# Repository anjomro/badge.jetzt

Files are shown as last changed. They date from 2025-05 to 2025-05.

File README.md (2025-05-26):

# badge.jetzt

## How to build the badge hardware

1. Get the PCB
2. Solder the ESP32-C3 module to the PCB
3. Solder the WS2812B LEDs to the PCB
   1. The LEDs have a white corner on one corner, this needs to be on the top left corner for both LEDs
4. Solder the OLED Display to the PCB
5. Solder the buttons to the PCB
6. Flash the software to the ESP32-C3 module
   1. Install [platformio](https://platformio.org/platformio-ide) or the [CLI](https://docs.platformio.org/en/latest/core/index.html)
   2. Clone the repository: `git clone git@github.com:anjomro/badge.jetzt.git`
   3. Upload the project, run `pio run -t upload`

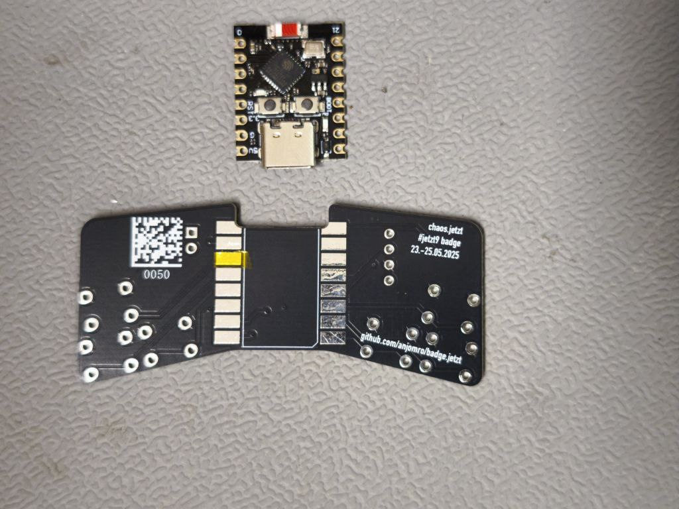
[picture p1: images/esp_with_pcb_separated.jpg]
ESP-C3 with PCB ESP-C3 with PCB separated

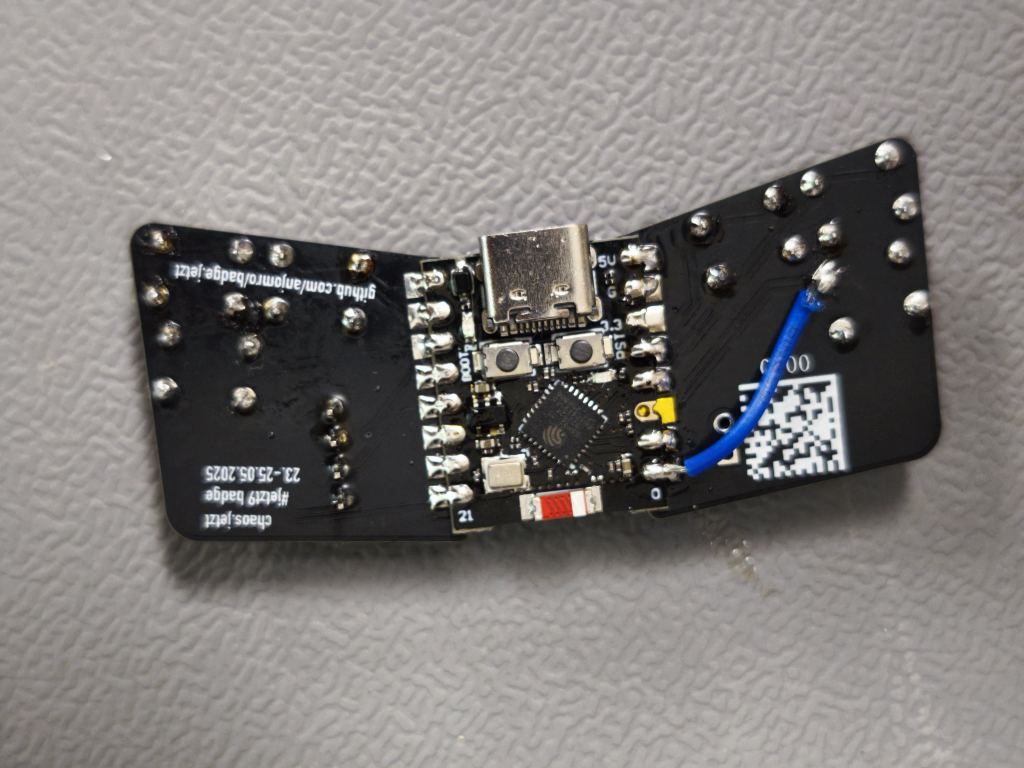
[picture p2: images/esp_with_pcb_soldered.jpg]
ESP-C3 with PCB soldered

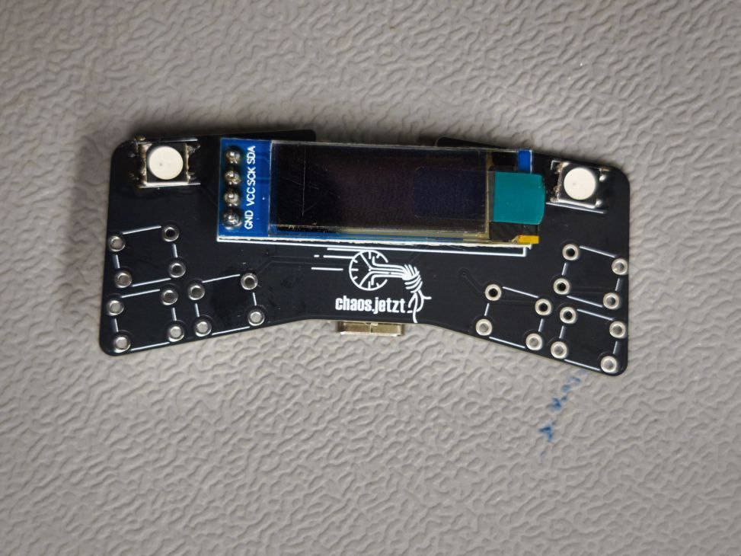
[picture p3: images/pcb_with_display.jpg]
PCB front with display PCB with display soldered on ti


## PlatformIO on different Systems:
**Arch**: `sudo pacman -Sy platformio-core`

**Debian/Ubuntu**: 

 1. PlatformIO installieren ([Platformio install](https://docs.platformio.org/en/latest/core/installation/methods/installer-script.html)), zum Beispiel:
    1. `wget -O get-platformio.py https://raw.githubusercontent.com/platformio/platformio-core-installer/master/get-platformio.py`
    2.  `python3 get-platformio.py`
2. Repo klonen: `git clone https://github.com/anjomro/badge.jetzt.git`
3. add PlatformIO Core binary directory to the system environment PATH variable (im bashrc), zum Beispiel
   1. `nano .bashrc`
   2. ganz unten `export PATH="$PATH:Your/Path/To/PlatformIO/bin/directory"` hinzufügen
   3. `source .bashrc`
4. udev rules [siehe Anleitung installieren](https://docs.platformio.org/en/latest/core/installation/udev-rules.html), zum Beispiel
   1. `curl -fsSL https://raw.githubusercontent.com/platformio/platformio-core/develop/platformio/assets/system/99-platformio-udev.rules | sudo tee /etc/udev/rules.d/99-platformio-udev.rules`
   2. `sudo service udev restart`
   3. physically unplug and reconnect your board
5. im badge.jetzt directory `pio run -t upload` ausführen

**Nix**:
```Bash
git clone 'https://github.com/anjomro/badge.jetzt'
cd badge.jetzt
nix develop
pio run -t upload
```

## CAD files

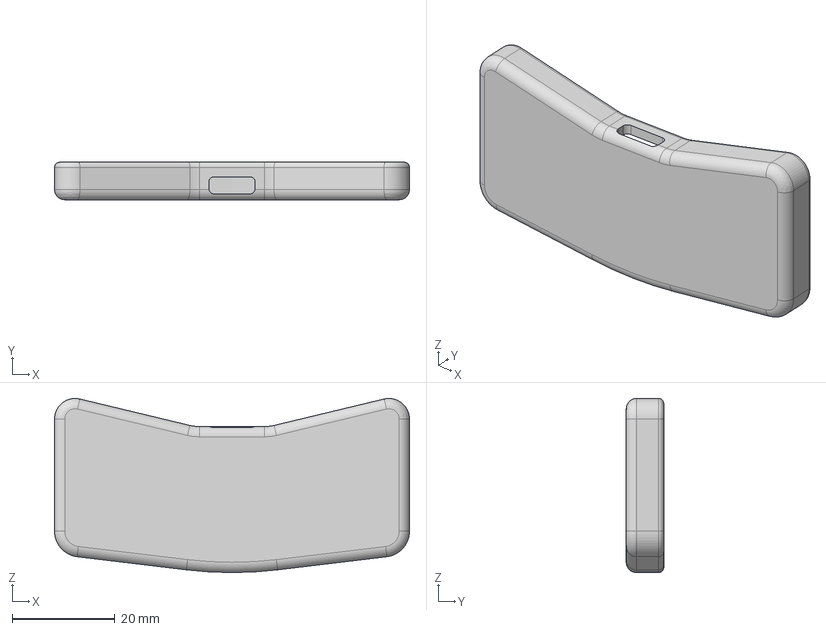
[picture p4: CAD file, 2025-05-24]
hardware/case/badge.jetzt-case.step
69.0 x 7.30 x 33.8 mm

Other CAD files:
hardware/case/badge.jetzt-case.stl

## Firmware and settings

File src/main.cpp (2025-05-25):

#include "base/display.h"
#include "base/led.h"
#include "base/button.h"
#include "base/pins.h"
#include "etherbloom/mandelbrot.h"
#include "irrlicht/menusystem/menusystem.h"

void button_test();

int choice;

void setup() {
    Serial.begin(115200);
    Serial.println("badge.jetzt");

    button::init();
    led::init();
    display::init();

    display::clearDisplay();
    display::println("Chaos.JETZT! #9");
    display::println("26.05.2025 in Leipzig");
    display::println("");
    display::println("ESP-C3 - v1.0");
    display::display();

    // Six example options
    const char* options[] = {
        "Button Test",
        "Mandelbrot",
        "Y.A.M.S",
    };
    choice = display::makeMenu("Menu Test", options, 3);

    display::clearDisplay();
    // Workaround due to weird print and println shifts
    display::println("Selected: " + String(options[choice]));
    display::println("");
    display::println("Waiting for 2 seconds");
    display::display();
    delay(2000);
}


void loop() {
    display::clearDisplay();

    switch (choice) {
        case 0:
            button_test();
        break;
        case 1:
            mandelbrot::print_mandelbrot_set();
        break;
        case 2:
            menusystem::launch();
        break;
    }
}

void button_test() {
    String msg_l = "";
    String msg_r = "";


    if (button::down(BTN1)) { led::set_l(255,0,0); msg_l = "BTN1: Left Red"; }
    else if (button::down(BTN2)) { led::set_l(0,255,0); msg_l = "BTN2: Left Green"; }
    else if (button::down(BTN3)) { led::set_l(0,0,255); msg_l = "BTN3: Left Blue"; }
    else
    {
        led::set_l(0,0,0);
        msg_l = "--";
    }
    if (button::down(BTN4)) { led::set_r(255,0,0); msg_r = "BTN4: Right Red"; }
    else if (button::down(BTN5)) { led::set_r(0,255,0); msg_r = "BTN5: Right Green"; }
    else if (button::down(BTN6)) { led::set_r(0,0,255); msg_r = "BTN6: Right Blue"; }
    else
    {
        led::set_r(0,0,0);
        msg_r = "--";
    }


    // Update display::display
    display::clearDisplay();
    display::println("Button Test");
    display::println(msg_l);
    display::println(msg_r);
    display::println("Press any button");
    display::println("to change color");
    display::display();

    delay(100);
}

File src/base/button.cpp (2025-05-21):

//
// Created by Anton Mrosek on 19.05.25.
//

#include "button.h"

namespace button
{
    void init()
    {
        // Buttons
        for (uint8_t pin : {BTN1, BTN2, BTN3, BTN4, BTN5, BTN6}) {
            pinMode(pin, INPUT_PULLDOWN);
        }
    }


    bool down(uint8_t pin) {
        if (pin == BTN6 || pin == BTN4)
        {
            // Special PullUp; Low = 2.5V, High = 3.3V
            // Workaround: analogRead to get the voltage
            int value = analogRead(pin);
            if (value > 4000) {
                return true;
            }
            return false;
        }
        return digitalRead(pin);
    }
}

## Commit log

2025-05-20 Add basic hardware abstraction for button, LED, and display functionality
2025-05-24 Add case files
    [badge.jetzt-case.step, badge.jetzt-case.stl]
2025-05-25 YAMS - yet another menu system
    menusystem und exampleapps hinzugefügt und in dsa bestehende menü
    eingebettet
    drawImage und setTextColor zu display.cpp hinzugefügt
